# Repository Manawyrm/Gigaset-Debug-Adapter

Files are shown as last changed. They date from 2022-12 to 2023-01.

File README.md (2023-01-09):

Gigaset-Debug-Adapter
=============================
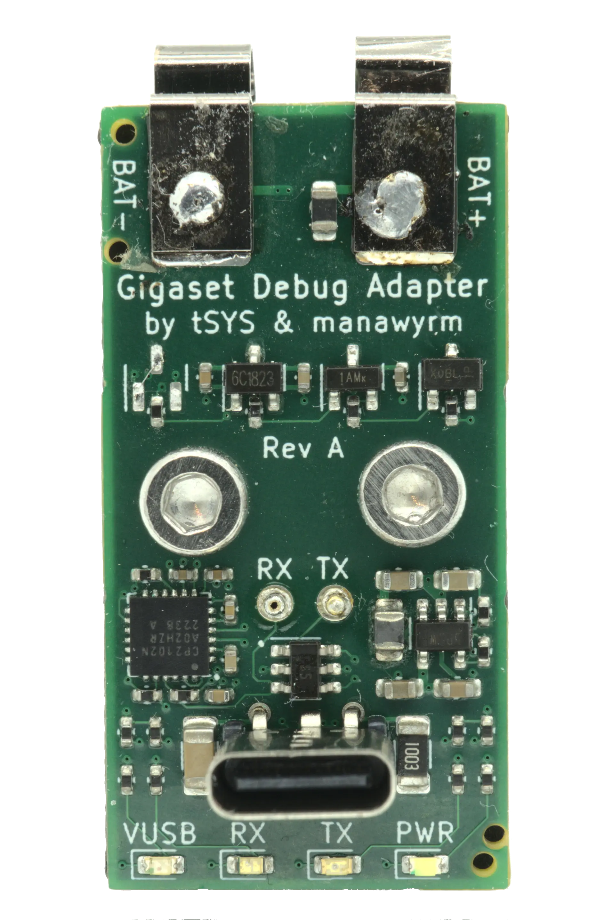
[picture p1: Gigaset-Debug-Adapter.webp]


### Overview

[Gigaset-Debug-Adapter](https://github.com/Manawyrm/Gigaset-Debug-Adapter) can be used with many Gigaset DECT phone models to access the internal UART.  
It's basically a 1.8V USB->UART converter, with switchable strapping logic and 3V step-down converter.

[dialog-cr16c-uart-boot](https://github.com/TobleMiner/dialog-cr16c-uart-boot) can be used to upload a stub to the phone through the boot ROM and access the SPI NOR flash chip.

https://user-images.githubusercontent.com/748791/209271987-683d4506-6c61-477d-b1db-ebee4b655a7c.mp4

### Manufacturing
The PCB can (and should) be assembled at [JLCPCBs](https://jlcpcb.com/) assembly service.  
Manufacturing files for the automatic assembly service can be found at `gerbers/RevB/Gigaset-Debug-Adapter/`.  
JLC can probably also manufacture the 3D printed adapter for you, altough this was never tested. Please report if you do.

Additionally, you will need:
- 2 Pogo pins. Tested with: 16,7 mm full length, 2,3 mm travel, 0.96 mm diameter
- 2 Keystone 5230 AAA battery contacts (2 slim pieces of tin sheet would probably work as well)
- 2 M3 threaded inserts (designed for CNCKitchen M3 x 5.7)
- 2 M3 machine screws
- 1 3D printable battery adapter (FDM with 0.3mm layer height, 35% infill worked well. Print upside down!)

Note: We've had trouble soldering to the Keystone 5230 using lead-free solder! Use leaded solder instead.

### Purchasing a DIY parts kit

sysmocom is making available a complete kit consisting of all the parts listed above which can be purchased via the [sysmocom webshop](https://shop.sysmocom.de/Gigaset-Debug-Adapter-DIY-kit/gset-dbg-ad-kit)

### CP2102N EEPROM

In order to enable the RX/TX LEDs, the internal EEPROM of the CP2102N USB->UART converter IC must be programmed to use the GPIO0 and GPIO1 pins as LED outputs.
This can be done eiher

* using SiLabs propritary Simplicity Studio,
* using the FOSS tool [ext/badge/cp2102 of cp210x-program](https://github.com/VCTLabs/cp210x-program)

#### EEPROM programming using Silabs Simplicity Studio

Screenshot of Simplicity Studio, showing the GPIO configs, with Alternate Functions being TX/RX Toggle

Simplicity Studio (and the experience of downloading it) is awful, be prepared and use a VM.   
This step is fully optional, you just lose the LEDs. Those are pretty and useful, but not required.

#### EEPROM programming using cp210x-program

The FOSS tool [cp210x-program](https://github.com/VCTLabs/cp210x-program) contains two separate programmers:
One python tool for CP2102, and the `ext/badge/cp2102` C program which we need here.

Do something like

```
./bin/cp2102 -p "Gigaset Debug Adapter" -g on
```

And then power-cycle the board to apply the new settings.

### Additional resources 

[Schematic - Rev. B](gerbers/RevB/Gigaset-Debug-Adapter/Gigaset-Debug-Adapter.pdf)  
[Bootloader utility - dialog-cr16c-uart-boot](https://github.com/TobleMiner/dialog-cr16c-uart-boot)  

### Errata
Rev.A: Bootloader Resistor logic is wrong, use Rev.B!

### Mechanicals
The battery adapter was designed using OpenSCAD. The definition file can be found as [battery-adapter.scad](battery-adapter.scad).

OpenSCAD will generate a .stl file, suitable for 3D printing. This file can be converted for use in KiCad using meshconv:
```bash
meshconv -c wrl battery-adapter.stl -o battery-adapter
```

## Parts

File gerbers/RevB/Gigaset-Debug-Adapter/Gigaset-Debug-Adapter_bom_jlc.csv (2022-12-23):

Comment | Designator | Footprint | LCSC Part #
1nF | C1 | C_1206_3216Metric | C35216
4.7uF | C2,C5,C11,C13 | C_0402_1005Metric | C23733
100n | C3,C4,C6 | C_0402_1005Metric | C1525
10uF | C7,C8 | C_0603_1608Metric | C19702
1uF | C9 | C_0402_1005Metric | C52923
22uF | C10,C12 | C_0603_1608Metric | C59461
RED (VBUS) | D1 | LED_0603_1608Metric | C2286
YLW (TX) | D2 | LED_0603_1608Metric | C72038
GRN (RX) | D3 | LED_0603_1608Metric | C72043
WHT (VCC) | D4 | LED_0603_1608Metric | C2290
600R@100MHz | FB1 | L_0805_2012Metric | C1017
USB_C_Receptacle | J1 | USB_Type_C_Straight_C168703 | C168703
2.2uH | L1 | L_0805_2012Metric_Pad1.15x1.40mm_HandSolder | C412023
MMBT3904 | Q1 | SOT-23 | C20526
AO3400A | Q2 | SOT-23 | C20917
100k HV | R1 | R_1206_3216Metric | C17900
22k | R2 | R_0402_1005Metric | C25768
47k | R3 | R_0402_1005Metric | C25792
5.1 kR | R4,R5 | R_0402_1005Metric | C25905
4.7k | R6 | R_0402_1005Metric | C25900
5.1k | R7,R11,R12,R15 | R_0402_1005Metric | C25905
10k | R8,R14 | R_0402_1005Metric | C25744
100k | R9,R10,R13 | R_0402_1005Metric | C25741
120k | R16,R18 | R_0402_1005Metric | C25750
470k | R17 | R_0402_1005Metric | C25790
CP2102N-Axx-xQFN24 | U1 | QFN-24-1EP_4x4mm_P0.5mm_EP2.6x2.6mm | C969151
SRV05-4 | U2 | SOT-23-6 | C85364
SY8088 | U3 | SOT-23-5 | C479072
XC6206P18xMR | U4 | SOT-23 | C2827651

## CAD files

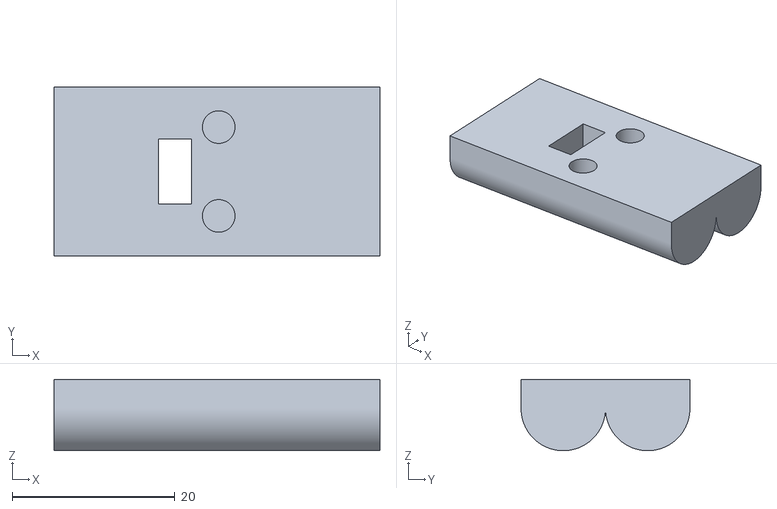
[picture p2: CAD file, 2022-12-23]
battery-adapter.stl
40.0 x 20.7 x 8.76

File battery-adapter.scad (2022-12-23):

// Written by Tobias Mädel <t.maedel@alfeld.de>
// https://github.com/manawyrm
// https://tbspace.de/

circle_segments = 360;
battery_diameter = 10.36;
battery_length   = 40.00;
battery_length_pole = 1.20;
battery_pole_diameter = 3.80;

pcb_height = 1.6;
platform_height = (battery_diameter / 2) - pcb_height;

pogo_passthru_length = 8;
pogo_passthru_height = 4;

// battery minus to pogo center
battery_to_pogo = 12.85;

// battery minus to screw hole center
battery_to_screw = 20.21;

// fit for M3 brass threaded insert
screw_hole_diameter = 4;
screw_hole_depth = 7.2;
screw_hole_distance = 5.45;

difference() {
    union() {
        // plattform for the PCB
        color("black")
            translate([0,0,battery_diameter / 2 + (platform_height / 2)])
                cube([
                    battery_length,
                    battery_diameter * 2,
                    platform_height
                ],center=true);

        // AAA batteries
        difference() {
            union() 
            {
                color("white")
                {
                    for (i=[0:1])
                    {
                        translate([
                            0,
                            (0.5 * battery_diameter) - (i * battery_diameter),
                            battery_diameter / 2
                        ])
                        {
                            // swapped polarity
                            rotate([0, 270 - (i * 180), 0])
                            {
                                // main battery
                                linear_extrude(height = battery_length, center = true)
                                    circle(d = battery_diameter, $fn=circle_segments);

                                // battery positive pole
                                //translate([0,0,battery_length / 2 + (battery_length_pole / 2)])
                                //    linear_extrude(height = battery_length_pole, center = true)
                                //        circle(d = battery_pole_diameter, $fn=circle_segments);
                            }
                        }
                    }
                }
            }
            translate([0,0,10])
            {
                 cube([
                        battery_length,
                        battery_diameter * 2,
                        platform_height
                    ],center=true);
             }
        }
    }

    // pogo pin hole
    translate([-1 * (battery_length / 2 - pogo_passthru_height / 2) + battery_to_pogo,
                0,
                battery_diameter / 2 + (platform_height / 2)
              ])
        cube([
            pogo_passthru_height,
            pogo_passthru_length,
            50
        ],center=true);
    
    // screw holes
    translate([-1 * (battery_length / 2) + battery_to_screw,
                screw_hole_distance,
                battery_diameter / 2 + (platform_height / 2)
              ])
        cylinder(h=screw_hole_depth,
                 r1=screw_hole_diameter / 2,
                 r2=screw_hole_diameter / 2,
                 center = true,
                 $fn=circle_segments);
                 
    translate([-1 * (battery_length / 2) + battery_to_screw,
                -screw_hole_distance,
                battery_diameter / 2 + (platform_height / 2)
              ])
        cylinder(h=screw_hole_depth,
                 r1=screw_hole_diameter / 2,
                 r2=screw_hole_diameter / 2,
                 center = true,
                 $fn=circle_segments);
}

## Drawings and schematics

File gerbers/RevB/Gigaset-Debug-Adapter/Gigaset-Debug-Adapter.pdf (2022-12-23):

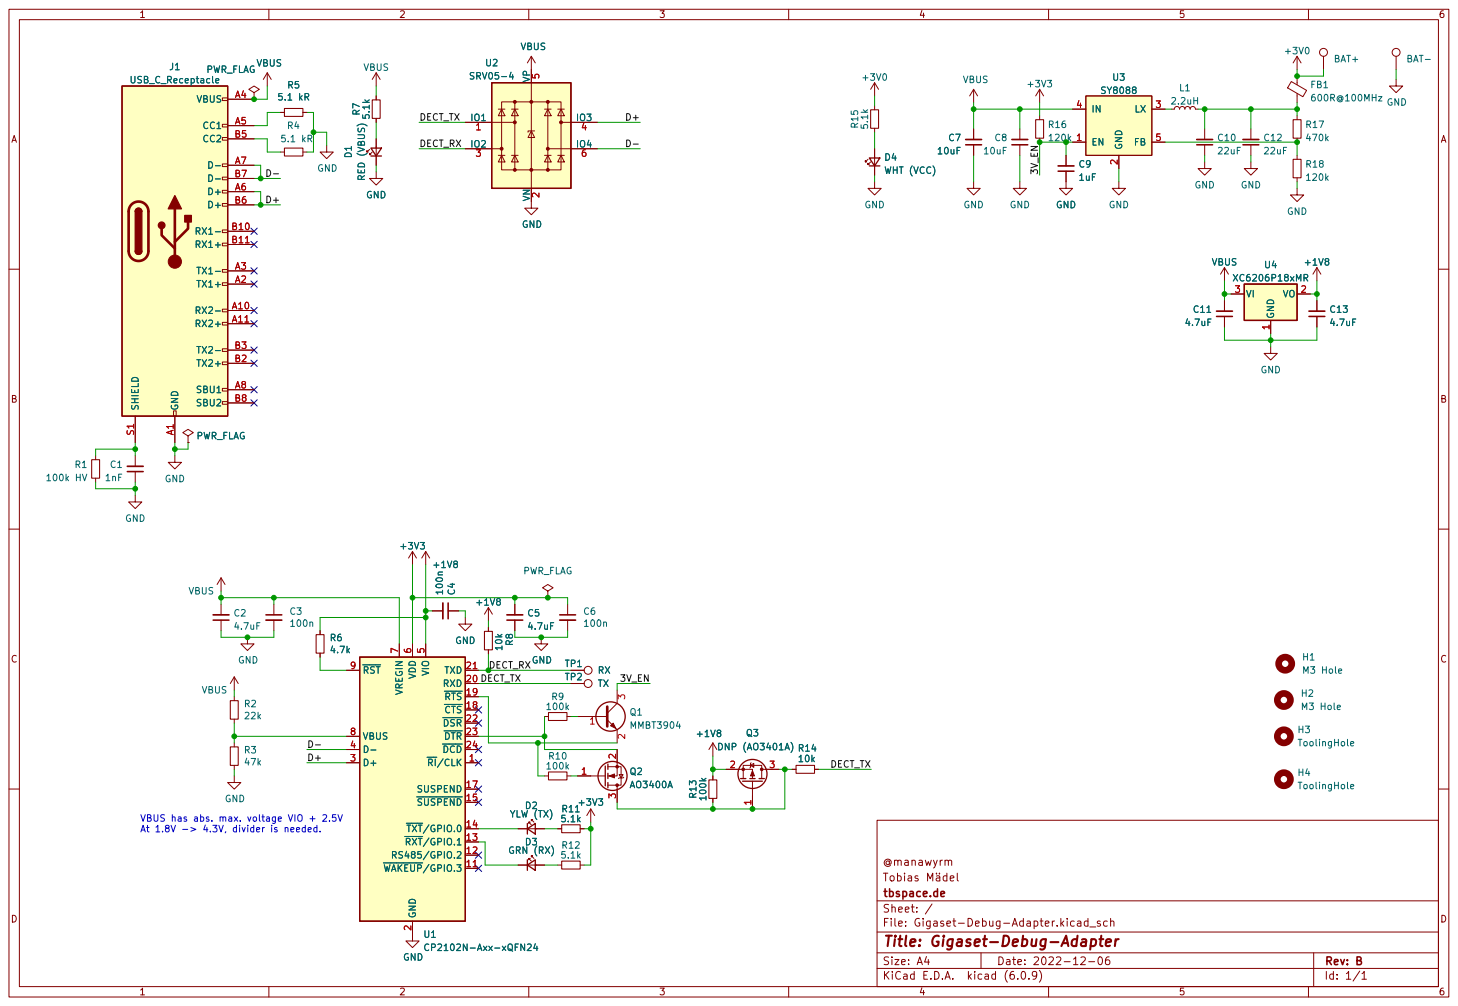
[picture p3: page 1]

5.1k D3 GRN (RX) D2 YLW (TX) D1 RED (VBUS) GND

7 VBUS 8 ~{RST} 9 U1CP2102N-Axx-xQFN24 GND R13 100k 1

2 RXD 20 TXD 21 ~{DSR}22 ~{DTR}23 ~{DCD}24 D+ 3 D- 4 VIO

VBUS has abs. max. voltage VIO + 2.5V
At 1.8V -> 4.3V, divider is needed.

D2 YLW (TX) D3 GRN (RX) R11

@manawyrm
File: Gigaset-Debug-Adapter.kicad_sch Sheet: / tbspace.de

Id: 1/1 Title: Gigaset-Debug-Adapter

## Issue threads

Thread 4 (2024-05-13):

Gigaset A170H Compatibility

TwistedBlizzard, 2024-05-13:
I've ordered my PCBs from JLCPCB and hope to recieve them shortly.

I'll be modifying one of them to test on an A170H handset which has it's debug pads in a different position.

If all goes well, I can submit a pull request with a modified PCB for A170H compatibility.

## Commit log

2022-12-10 initial commit 2
    [Gigaset-Debug-Adapter.kicad_pcb, Gigaset-Debug-Adapter.kicad_sch]
2022-12-11 Everything but battery contacts
    [Gigaset-Debug-Adapter.kicad_pcb, Gigaset-Debug-Adapter.kicad_sch, battery-adapter.scad]
2022-12-11 Place and route battery contacts
    [Gigaset-Debug-Adapter.kicad_pcb]
2022-12-11 Add silkscreen markings
    [Gigaset-Debug-Adapter-B_Cu.gbr, Gigaset-Debug-Adapter-B_Mask.gbr, Gigaset-Debug-Adapter-B_Paste.gbr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]
2022-12-23 Add updated 3D model, README and GPLv3 license
    [Gigaset-Debug-Adapter.kicad_pcb, battery-adapter.scad, battery-adapter.stl]
2022-12-23 Add RevB with strapping fixes
    [Gigaset-Debug-Adapter-B_Cu.gbr, Gigaset-Debug-Adapter-B_Mask.gbr, Gigaset-Debug-Adapter-B_Paste.gbr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]
2022-12-23 Fix broken RevB, was missing the second mounting hole
    [Gigaset-Debug-Adapter-B_Cu.gbr, Gigaset-Debug-Adapter-B_Mask.gbr, Gigaset-Debug-Adapter-B_Paste.gbr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]
2022-12-23 Add missing info about screws and threaded insert
